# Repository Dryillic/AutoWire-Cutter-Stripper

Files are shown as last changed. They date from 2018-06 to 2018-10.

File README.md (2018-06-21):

# AutoWire-Cutter-Stripper

This repository is for documenting the process and project of creating our own automatic wire cutter.
The device will be able to take input from the user regarding wire length, options and number of wires.

The original inspiration for this project came from Reddit user "Maclsk" on the subreddit /r/specializedtools, link here: https://www.reddit.com/r/specializedtools/comments/78wd32/i_made_a_specialized_tool_for_cutting_wire/
Our goal is to create a similar device with autostripping for our workplace.

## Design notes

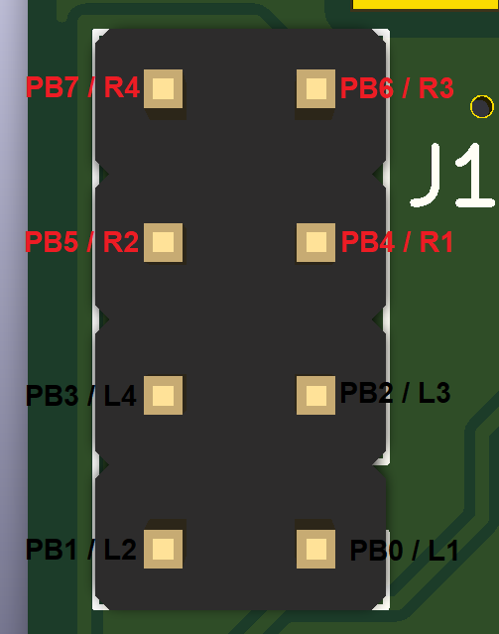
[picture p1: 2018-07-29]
Keypad Pinout.png

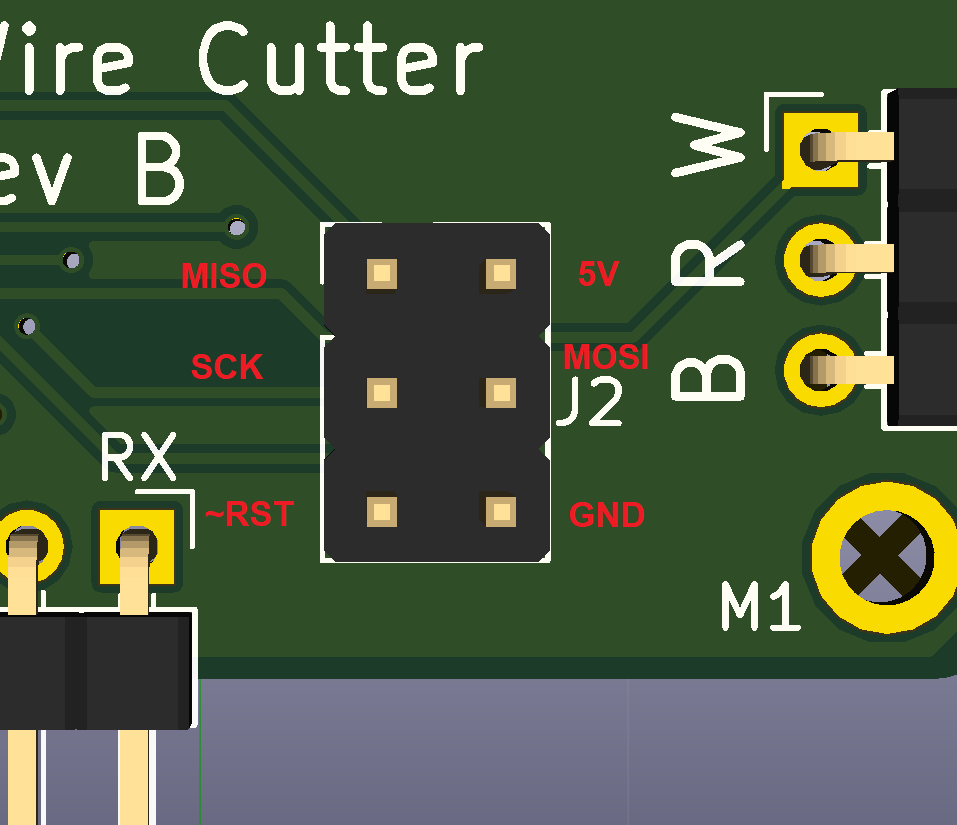
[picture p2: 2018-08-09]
SPI Connections.png

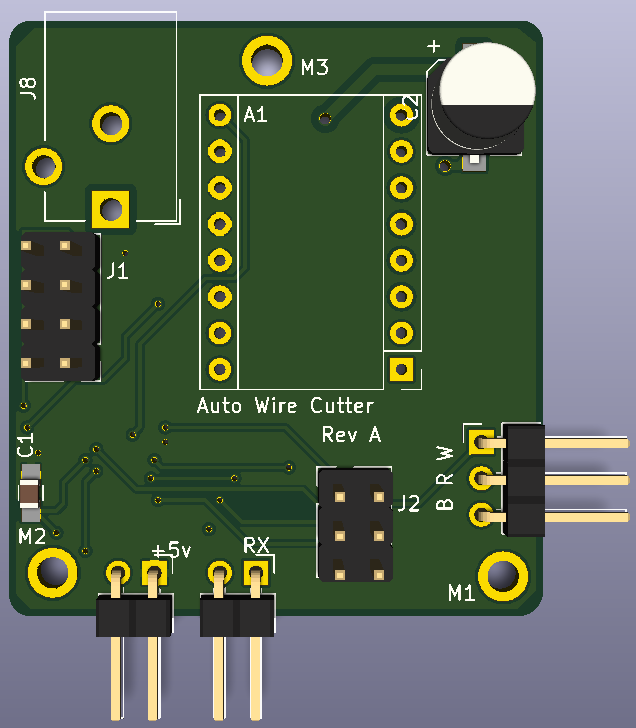
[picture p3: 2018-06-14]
Board Top.png

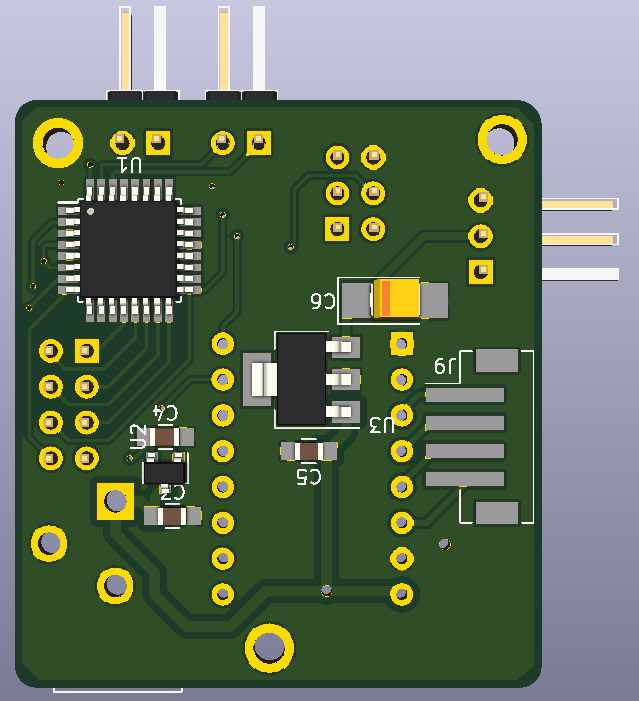
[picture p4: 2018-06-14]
Board Bottom.png

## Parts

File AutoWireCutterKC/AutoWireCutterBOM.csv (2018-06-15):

Source: | C:/Users/dnatov/Documents/GitHub/AutoWire-Cutter-Stripper/AutoWireCutterKC/AutoWireCutterKC.sch
Date: | 6/14/2018 12:04
Tool: | Eeschema 4.0.7
Generator: | C:/Program Files (x86)/KiCad/bin/scripting/plugins/bom_csv_grouped_by_value.py
Component Count: | 20
Individual Components:
Item | Qty | Reference(s) | Value | LibPart | Footprint | Datasheet
 |  | A1 | Pololu_Breakout_DRV8825 | Driver_Motor:Pololu_Breakout_DRV8825 | Module:Pololu_Breakout-16_15.2x20.3mm
 |  | C1 | 100n | device:C | Capacitors_SMD:C_0805_HandSoldering
 |  | C2 | 100u | device:CP | Capacitors_SMD:CP_Elec_6.3x7.7
 |  | C3 | 1u | device:C | Capacitors_SMD:C_0805_HandSoldering
 |  | C4 | 1u | device:C | Capacitors_SMD:C_0805_HandSoldering
 |  | C5 | 1u | device:C | Capacitors_SMD:C_0805_HandSoldering
 |  | C6 | 3.3u | device:CP1 | Capacitors_Tantalum_SMD:CP_Tantalum_Case-B_EIA-3528-21_Hand
 |  | J1 | LCD I/O | conn:Conn_01x08 | Pin_Headers:Pin_Header_Straight_2x04_Pitch2.54mm
 |  | J2 | ISP | conn:Conn_02x03_Odd_Even | Pin_Headers:Pin_Header_Straight_2x03_Pitch2.54mm
 |  | J3 | LCD Serial | conn:Conn_01x02 | Pin_Headers:Pin_Header_Angled_1x02_Pitch2.54mm
 |  | J5 | LCD Power | conn:Conn_01x02 | Pin_Headers:Pin_Header_Angled_1x02_Pitch2.54mm
 |  | J6 | Servo | conn:Conn_01x03 | Pin_Headers:Pin_Header_Angled_1x03_Pitch2.54mm
 |  | J8 | Barrel_Jack | conn:Barrel_Jack | Connectors:Barrel_Jack_CUI_PJ-102AH
 |  | J9 | Stepper | conn:Conn_01x04 | S4B-PH-SM4-TB
 |  | M1 | Conn_01x01_Male | conn:Conn_01x01_Male
 |  | M2 | Conn_01x01_Male | conn:Conn_01x01_Male
 |  | M3 | Conn_01x01_Male | conn:Conn_01x01_Male
 |  | U1 | ATMEGA328P-AU | atmel:ATMEGA328P-AU | Housings_QFP:TQFP-32_7x7mm_Pitch0.8mm
 |  | U2 | MCP1700_SOT23 | regul:MCP1700-5002E_SOT23 | TO_SOT_Packages_SMD:SOT-23
 |  | U3 | LT1129-5.0_SOT223 | regul:LT1129-5.0_SOT223 | TO_SOT_Packages_SMD:SOT-223
Collated Components:
Item | Qty | Reference(s) | Value | LibPart | Footprint | Datasheet
1 | 1 | A1 | Pololu_Breakout_DRV8825 | Driver_Motor:Pololu_Breakout_DRV8825 | Module:Pololu_Breakout-16_15.2x20.3mm
2 | 1 | C1 | 100n | device:C | Capacitors_SMD:C_0805_HandSoldering
3 | 1 | C2 | 100u | device:CP | Capacitors_SMD:CP_Elec_6.3x7.7
4 | 3 | C3, C4, C5 | 1u | device:C | Capacitors_SMD:C_0805_HandSoldering
5 | 1 | C6 | 3.3u | device:CP1 | Capacitors_Tantalum_SMD:CP_Tantalum_Case-B_EIA-3528-21_Hand
6 | 1 | J1 | LCD I/O | conn:Conn_01x08 | Pin_Headers:Pin_Header_Straight_2x04_Pitch2.54mm
7 | 1 | J2 | ISP | conn:Conn_02x03_Odd_Even | Pin_Headers:Pin_Header_Straight_2x03_Pitch2.54mm
8 | 1 | J3 | LCD Serial | conn:Conn_01x02 | Pin_Headers:Pin_Header_Angled_1x02_Pitch2.54mm
9 | 1 | J5 | LCD Power | conn:Conn_01x02 | Pin_Headers:Pin_Header_Angled_1x02_Pitch2.54mm
10 | 1 | J6 | Servo | conn:Conn_01x03 | Pin_Headers:Pin_Header_Angled_1x03_Pitch2.54mm
11 | 1 | J8 | Barrel_Jack | conn:Barrel_Jack | Connectors:Barrel_Jack_CUI_PJ-102AH
12 | 1 | J9 | Stepper | conn:Conn_01x04 | Pin_Headers:Pin_Header_Straight_1x04_Pitch2.54mm
13 | 3 | M1, M2, M3 | Conn_01x01_Male | conn:Conn_01x01_Male
14 | 1 | U1 | ATMEGA328P-AU | atmel:ATMEGA328P-AU | Housings_QFP:TQFP-32_7x7mm_Pitch0.8mm
15 | 1 | U2 | MCP1700_SOT23 | regul:MCP1700-5002E_SOT23 | TO_SOT_Packages_SMD:SOT-23
16 | 1 | U3 | LT1129-5.0_SOT223 | regul:LT1129-5.0_SOT223 | TO_SOT_Packages_SMD:SOT-223

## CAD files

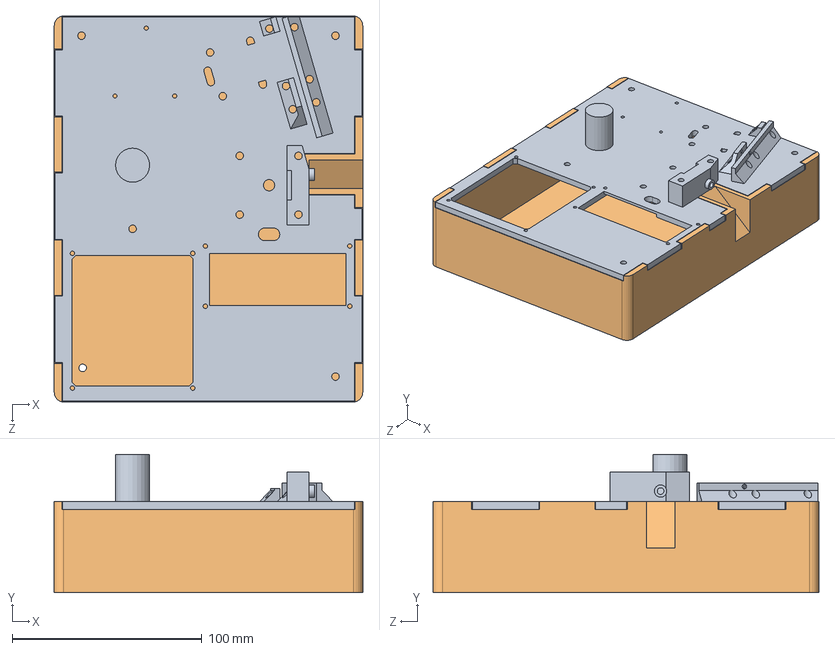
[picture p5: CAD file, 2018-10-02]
CAD Models/AutoWireCutter Assem.SLDASM
162.8 x 73.0 x 203.7 mm
Base Plate
Base

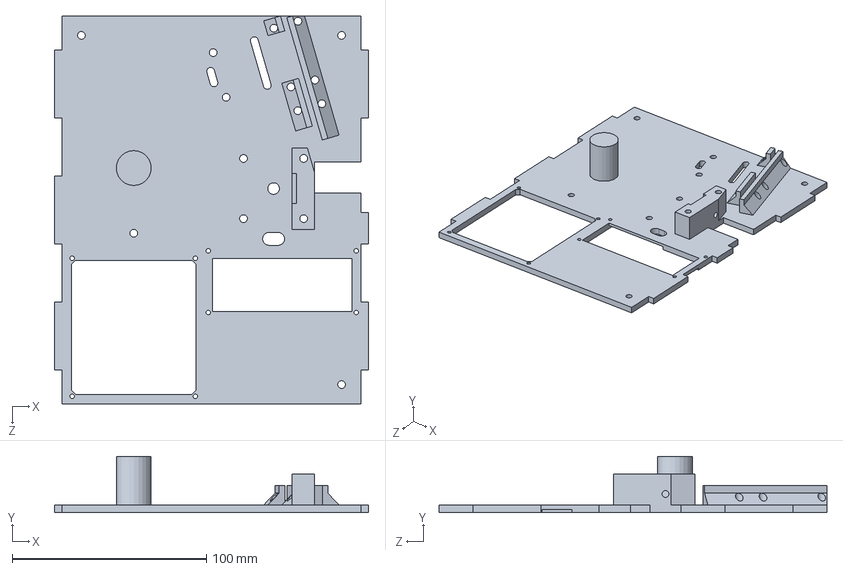
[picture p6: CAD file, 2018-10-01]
CAD Models/Base Plate Assembly.SLDPRT
162.0 x 29.0 x 199.9 mm

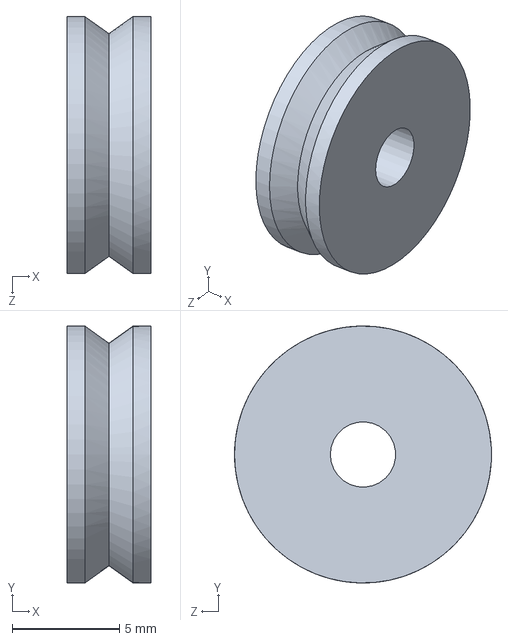
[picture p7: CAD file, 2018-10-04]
CAD Models/Idler.SLDPRT
3.94 x 12.0 x 12.0 mm

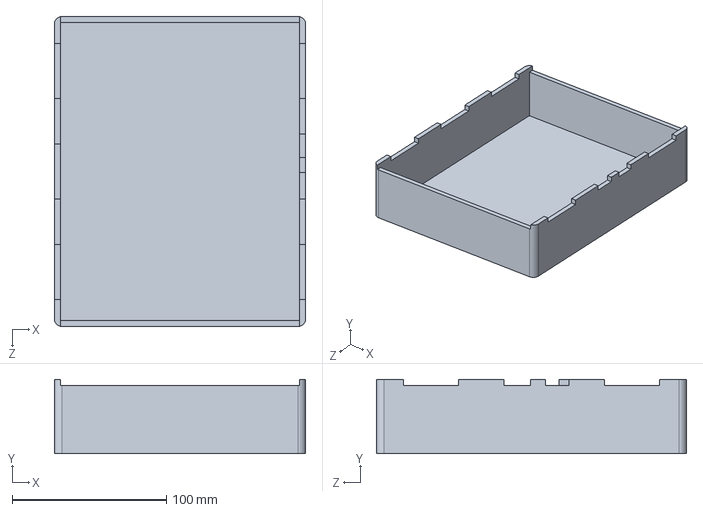
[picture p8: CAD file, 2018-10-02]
CAD Models/Base.SLDPRT
162.8 x 48.0 x 200.7 mm

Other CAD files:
CAD Models/Base Plate.SLDPRT
CAD Models/Base Plate.STL
CAD Models/Base.STL
CAD Models/Idler.STL

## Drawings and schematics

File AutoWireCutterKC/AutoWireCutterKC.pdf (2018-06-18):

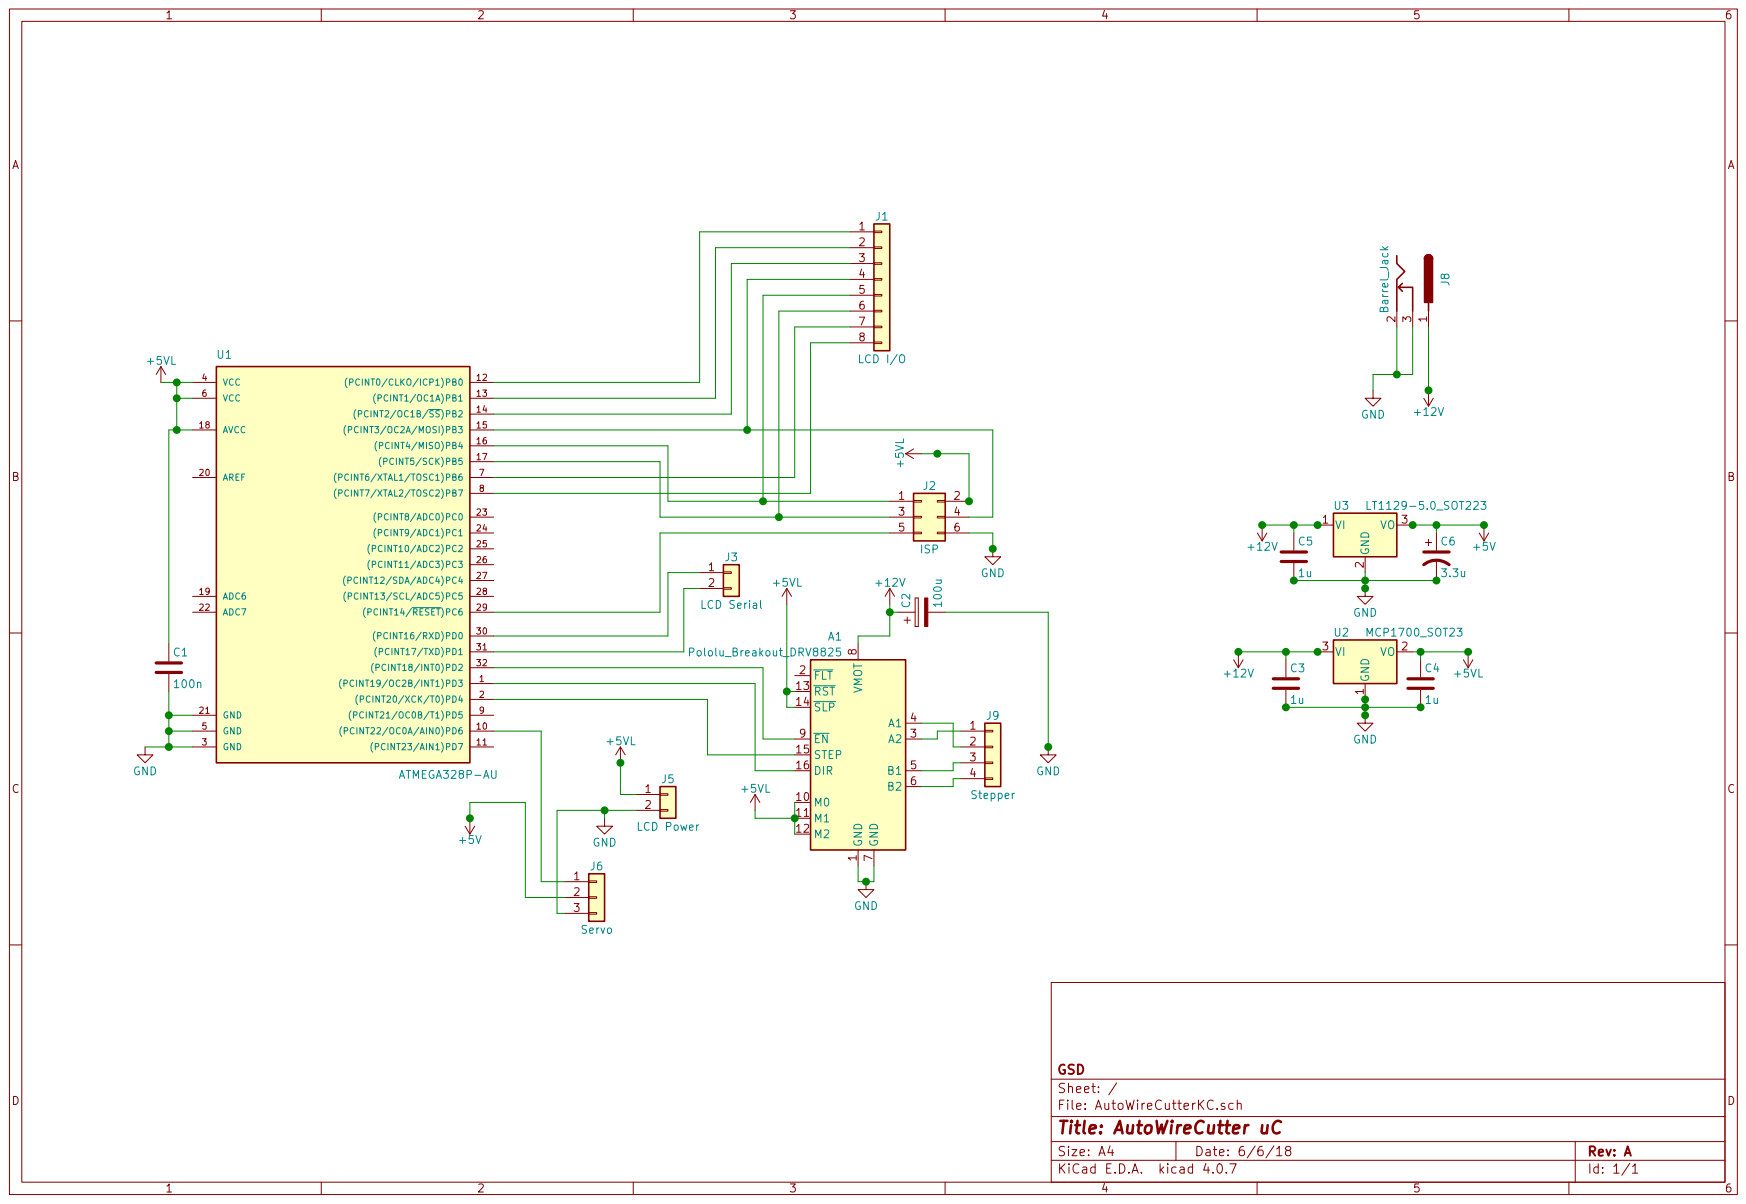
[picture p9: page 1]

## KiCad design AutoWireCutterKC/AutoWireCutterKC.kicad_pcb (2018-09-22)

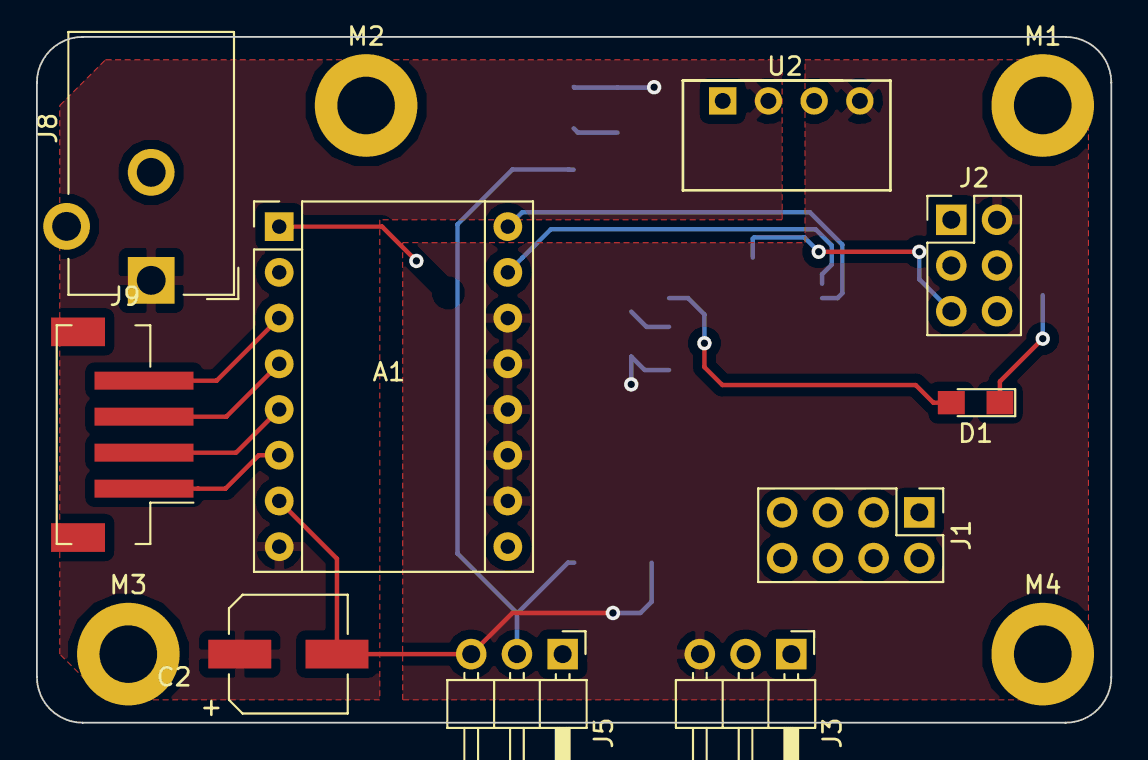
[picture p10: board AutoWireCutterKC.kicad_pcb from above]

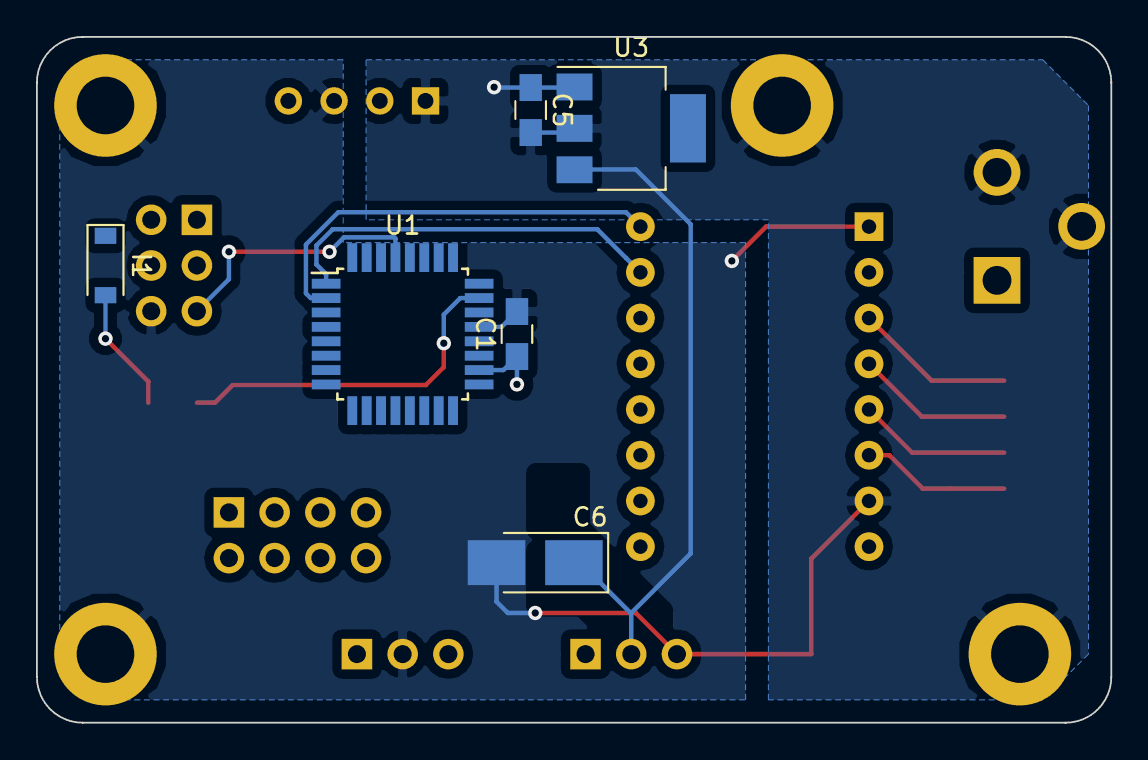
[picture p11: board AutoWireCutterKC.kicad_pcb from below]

Board: 2 copper layers, 59.7 x 38.1 mm, 20 parts (6 on the bottom side), 25 nets.

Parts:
A1: Pololu_Breakout_DRV8825; Pololu_Breakout-16_15.2x20.3mm
C1: 100n; C_0805_HandSoldering
C2: 100u; CP_Elec_6.3x7.7
C5: 1u; C_0805_HandSoldering
C6: 3.3u; CP_Tantalum_Case-B_EIA-3528-21_Hand
D1: LED; LED_0805_HandSoldering
I1: NSI50010YT1G; D_SOD-123
J1: LCD I/O; Pin_Header_Straight_2x04_Pitch2.54mm
J2: ISP; Pin_Header_Straight_2x03_Pitch2.54mm
J3: LCD; Pin_Header_Angled_1x03_Pitch2.54mm
J5: Servo; Pin_Header_Angled_1x03_Pitch2.54mm
J8: Barrel_Jack; Barrel_Jack_CUI_PJ-102AH
J9: Stepper; JST_PH_B4B_StressReliefCorrect
M1, M2, M3, M4: Conn_01x01_Male; MountingHole_3.2mm_M3_ISO7380_Pad
U1: ATMEGA328P-AU; TQFP-32_7x7mm_Pitch0.8mm
U2: CRE1S1205SC; CRE1S1205SC_DC_to_DC
U3: LT1129-5.0_SOT223; SOT-223

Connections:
+5V: C6.1, J5.2, U3.3
+5VL: A1.10, A1.11, A1.12, A1.13, A1.14, C1.1, J2.2, J3.3, U1.4, U1.6, U1.18, U2.4
+12V: A1.8, C2.1, C5.1, J8.1, U2.2, U3.1
GND: A1.7, C2.2, C5.2, C6.2, I1.1, J5.3, J8.2, J8.3, M2.1, M3.1, U2.1, U3.2
GNDREF: A1.1, C1.2, J2.6, J3.2, M1.1, M4.1, U1.3, U1.5, U1.21, U2.3
unnamed: A1.3, J9.4
unnamed: A1.4, J9.3
unnamed: A1.5, J9.2
unnamed: A1.6, J9.1
unnamed: A1.9, U1.32
unnamed: A1.15, U1.1
unnamed: A1.16, U1.2
unnamed: D1.1, I1.2
unnamed: D1.2, U1.23
unnamed: J1.1, U1.12
unnamed: J1.2, U1.13
unnamed: J1.3, U1.14
unnamed: J1.4, J2.4, U1.15
unnamed: J1.5, J2.1, U1.16
unnamed: J1.6, J2.3, U1.17
unnamed: J1.7, U1.7
unnamed: J1.8, U1.8
unnamed: J2.5, U1.29
unnamed: J3.1, U1.31
unnamed: J5.1, U1.10

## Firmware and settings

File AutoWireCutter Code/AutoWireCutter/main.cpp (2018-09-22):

/*
 * AutoWireCutter.cpp
 *
 * Created: 7/29/2018 12:19:06 PM
 * Authors : Dana Natov, Keith Tulley
 * 
 */ 

#define F_CPU 8000000UL /* 8Mhz clock rate */
#define BAUD 2400
#define USART_BAUDRATE 2400
#define BAUD_PRESCALE (((F_CPU / (USART_BAUDRATE * 16UL))) - 1)
#define display_On 0x16 /*  Parralax cmd: Display on with no cursor and no blink */
#define first_position 0x80 /* Parralax cmd: Move cursor to line 0 position 0 */
#define form_feed 0x0C /* Parralax cmd: Clear all text, move to line 0 pos 0 */
#define line_feed 0x0A /* Parralax cmd: Cursor moved to next line */
#define backlight_on 0x11 /* Parralax cmd: LCD Backlight on */
#define backlight_off 0x12 /* Parralax cmd: LCD Backlight off */
volatile int button_down;
#define BUTTON_MASK (1<<PB4)  //	Keypad input, R1 on Blue Keypad
#define BUTTON_MASK1 (1<<PB5) //	Keypad input, R2 on Blue Keypad
#define BUTTON_MASK2 (1<<PB6) //	Keypad input, R3 on Blue Keypad
#define BUTTON_MASK3 (1<<PB7) //	Keypad input, R4 on Blue Keypad
#define BUTTON_PIN PINB

#include <util/delay.h>
#include <avr/io.h>
#include <stdio.h>
#include "Servo.h"
#include "DRV8825.h"

static inline void ser_init() /* I'm told Static Inline functions are great for things that are called once (like initializing serial) */
{
	UCSR0B = (1 << TXEN0) | (1 << RXEN0); /* Serial Transmit and Recieve Enable */
	UCSR0C = (0 << USBS0) | (3 << UCSZ00); /* Set Stop Bit Length (1 Stop Bit) and Frame Length (8 data bits). No parity */
	UBRR0H = (unsigned char)(BAUD_PRESCALE >> 8); /* Load upper 8-bits of baud rate value into high byte of UBBR0 register */
	UBRR0L = (unsigned char)BAUD_PRESCALE; /* Load lower 8-bits of the baud rate value into low byte of UBBR0 register */
	while ( !( UCSR0A & (1 << UDRE0)));
	; /* Wait for an empty Transmit Buffer */
	UDR0 = display_On; /* Turn LCD on with no blink and no cursor */
	
}

static inline void debounce(void)
{
	// Counter for number of equal states
	static uint8_t count = 0;
	// Keeps track of current (debounced) state
	uint8_t button_state = 0;

	// Check if button is high or low for the moment
	uint8_t current_state = ((~BUTTON_PIN & BUTTON_MASK) | (~BUTTON_PIN & BUTTON_MASK1) | (~BUTTON_PIN & BUTTON_MASK2) | (~BUTTON_PIN & BUTTON_MASK3)) != 0; // This is what allows multiple buttons to be debounced
	
	
	// Original Debounce
	if (current_state != button_state) {
		// Button state is about to be changed, increase counter
		count++;
		if (count >= 4) {
			// The button have not bounced for four checks, change state
			button_state = current_state;
			// If the button was pressed (not released), tell main so
			if (current_state != 0) {
				button_down = 1;
			}
			count = 0;
		}
		} else {
		// Reset counter
		count = 0;
	}
}

unsigned char keypad(void){	// Define the function to return which key is pressed
	unsigned char key;	//which key is pressed?
	unsigned char portb_pin;
	
	unsigned char keypad_column[4] = {7,6,5,4};	//Pins b7, 6, 5, 4 of Port B control keypad columns
	unsigned char keypad_row[4] = {3,2,1,0};	// Pins b3, 2, 1, 0 of Port B control keypad rows
	unsigned char keypad_array[4][4] ={	//Array contains all
		{'1','2','3','A'},
		{'4','5','6','B'},
		{'7','8','9','C'},
		{'*','0','#','D'}
	};
	unsigned char column;
	unsigned char row;

	
	for (column=0; column<4; column++){	//
		PORTB = ~(1<<(keypad_column[column]));
		_delay_ms(20);
		portb_pin = PINB;	//read the value from port B
		for(row=0; row<4; row++){
			if((portb_pin & (1<<(keypad_row[row])))==0) {
				key = keypad_array[column][row];	// search for the corresponding element in keypad array
				return (key);	// return the answer, which key is pressed?
			}
		}
	}
}



int printCHAR(char character, FILE *stream) /* Has printchar become a stream */
{
	

	while ((UCSR0A & (1 << UDRE0)) == 0) {}; /* While the transmit flag is active, the serial buffer is a character */

	UDR0 = character;

	return 0;
}

/*C only function that should have been included in compiler by now, 
check out http://savannah.nongnu.org/bugs/?36970. Function call moved to Main
for proper scope*/
//FILE uart_str = FDEV_SETUP_STREAM(printCHAR, NULL, _FDEV_SETUP_RW); /* Sets up "printf" */

int main(void)
{
	static FILE uart_str;
	fdev_setup_stream(&uart_str,printCHAR,NULL,_FDEV_SETUP_WRITE);
	
	DDRB = 0xF0;	//Configure Port B, Pins b7 to b4 are output. Pins b3 to b0 are input.
	// CTC for Timer 2 Setup
	//Edit by Dana, Set Timer to NOT use pin toggle, very important for proper Stepper function
	TCCR2A |= (1<<WGM21);	// Configure Timer 2 to CTC (Clear on timer compare) mode?????????????????????????????
	OCR2A = 260; // Set CTC Value for ~30HZ (From (8mHz Clock / 1024 prescaler) / (target of 30 HZ) = ~260)
	TCCR2B |= ((1<<CS20) | (1<<CS21) | (1<<CS22)); 	// Setup Timer for 8 mHz with a 1024 prescale
	
	// UART Link
	stdout = &uart_str; /* Links stdout and stream from file we set up */
	
	// Serial Init, LCD Backlight on
	ser_init(); /* Serial Initialize */
	UDR0 = backlight_on; /* Turn on LCD backlight */
	
	//Create Servo Object and Init
	Servo MainServo;
	MainServo.Intialize();
		
	//Create Stepper Object and Init
	DRV8825 MainStepper;
	MainStepper.Initialize();
	
	_delay_ms(1000);
	
	//Set External Interrupts
	sei();
	
	// Scratchpad variable
	int digit;	/* Temporary variable to hold the value of which key is pressed */

	//Init LCD splash screen
	!( UCSR0A & (1 << UDRE0));
	UDR0 = form_feed;
	_delay_ms(5);
	UDR0 = backlight_on;
	printf("Welcome!");
	
	while(1)
	{
		if (TIFR2 & (1<<OCF2A)) // If the CTC Throws it's flag at OCF2A (Your timer has elapsed)
		{
			debounce();
			
			if (button_down)
			{
				//printf("Hello");
				button_down = 0;
				digit = keypad();	/* Call the  function "keypad" to return the value of key pressed, and hold it with variable "digit" */
				switch(digit) /* Now evaluate value of "digit" to match with the LED pattern needed to be exported to Port B */
				{
					case '0':
						MainStepper.Runtostep(6400,true);
						_delay_ms(200);
						while ( !( UCSR0A & (1 << UDRE0))); /* Wait for serial buffer to clear, clear screen, turn on backlight, display text */
						UDR0 = form_feed;
						_delay_ms(5);
						UDR0 = backlight_on;
						printf("Rotating Stepper!");
						break;
					case '1':
					case '2':
					case '3':
					case '4':
					case '5':
					case '6':
					case '7':
						while ( !( UCSR0A & (1 << UDRE0))); /* Allows cases 1-7 to fall through the switch-case */
						UDR0 = form_feed;
						_delay_ms(5);
						UDR0 = backlight_on;
						printf("The # is:\r");
						printf("%c", digit);
						_delay_ms(50);
						break;
					case '8':
						MainServo.Enable(true);
						_delay_ms(200);
						MainServo.MoveToAngle(100);
						_delay_ms(200);
						MainServo.Enable(false);
						while ( !( UCSR0A & (1 << UDRE0))); /* Wait for serial buffer to clear, clear screen, turn on backlight, display text */
						UDR0 = form_feed;
						_delay_ms(5);
						UDR0 = backlight_on;
						printf("Rotating Servo!");
						break;
					case '9':
						while ( !( UCSR0A & (1 << UDRE0))); /* Wait for serial buffer to clear, clear screen, turn on backlight, display text */
						UDR0 = form_feed;
						_delay_ms(5);
						UDR0 = backlight_on;
						printf("The # is:\r");
						printf("%c", digit);
						_delay_ms(50);
						break;
					
					case 'A':
					case 'B':
					case 'C':
					case 'D':
					case '*':
					case '#':
					while ( !( UCSR0A & (1 << UDRE0))); /* Wait for serial buffer to clear, clear screen, turn on backlight, display text */
					UDR0 = form_feed;
					_delay_ms(5);
					UDR0 = backlight_on;
					printf("The # is:\r");
					printf("%c", digit);
					_delay_ms(50);
					break;
				}
			}
			TIFR2 = (1<<OCF2A); // Clear CTC flag by writing a logic 1 to it
		}	
	}
	return(1);
}

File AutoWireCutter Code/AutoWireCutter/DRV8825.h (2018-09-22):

#pragma once
#include <avr/io.h>
#include <avr/interrupt.h>

volatile long countStepper=0;

class DRV8825 {
	bool enableCont, directionCont;
	bool dir, enbl;
	int stepCount;
	public:
	void Enable(bool);
	void Direction(bool);
	void Initialize();
	void Runtostep(int, bool);
	bool directionRot() {return dir;}
	bool enablestatus() {return enbl;}
};

void DRV8825::Initialize()
{
	PORTD = (1 << PORTD2);
	DDRD |= (1 << PORTD2) | (1 << PORTD3) | (1 << PORTD4); //set ports 2,3,4 to output (6 is output for the servo)
	TCCR1B |= (1 << WGM12); //Set CTC bit timer 1
	OCR1A = 48; //Set tick amount to 48 for 10.5kHz Square Wave, (Toggle output)
	TIMSK1 = (1 << OCIE1A); //Set ISR interrupt
	
	/*note: the timer actually has a frequency of 10.5kHz * 2 = ~21kHz
	The ISR is a port toggle so this frequency has to be double for both rising and falling edges of square wave*/
	
	//SET IN MAIN INSTEAD
	//sei(); //Set I bit. aka set external interrupt
}

void DRV8825::Enable (bool enableCont) { //Enable Stepper Controller uses PORTD2
	if (enableCont) {
		enbl = true;
		PORTD = (0 << PORTD2);
	}
	else {
		enbl = false;
		PORTD = (1 << PORTD2);
	}	
}

void DRV8825::Direction(bool directionCont) { //Set Stepper Direction uses PORTD3
	if (directionCont) { //true is counter-clockwise, the direction the wire normally feeds
	dir = true;
	PORTD = (1 << PORTD3);
	}
	else { //false is clockwise
	dir = false;
	PORTD = (0 << PORTD3);
	}	
}

void DRV8825::Runtostep(int stepCount, bool directionCont) { //200*32 microsteps per revolution meaning 6400 is one revolution
	UCSR0B = (0 << TXEN0) | (0 << RXEN0); /* Serial Transmit and Recieve Disable */
	TCCR1B |= (1 << CS11); //Timer pre-scaler set to div 8 START TIMER
	
	if (countStepper > 2000000000) {
		countStepper = 0;
	}
	long countcurrent = countStepper;
	this->Direction(directionCont);
	while (countStepper < (countcurrent+stepCount+1)) { //+1 to account for setup time when the enable pin goes high
		this->Enable(true);
	}
	this->Enable(false);
	
	TCCR1B |= (0 << CS11); //Timer pre-scaler set to off STOP TIMER
	UCSR0B = (1 << TXEN0) | (1 << RXEN0); /* Serial Transmit and Recieve Enable */
}

ISR(TIMER1_COMPA_vect) //Runs every 10.5khz
{
	countStepper++; //take care not to overflow. Overflows in about 2 days.
	PORTD ^= (1 << PORTD4); //toggle port d4 for square wave
}

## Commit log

2018-01-05 Add files via upload
    Serial Tx/Rx enable for the 328P. Also sets up a stream to serial so "printf" can be used to send ascii to a serial target.
2018-05-20 Added Stepper Library and Test Code
2018-05-20 Added demo video of Stepper Driver
2018-05-26 Create Servo Library Folder
2018-05-26 Added Servo Library and Ex Code
2018-05-26 Move to Stepper Library Folder
2018-05-26 Move ex code to StepperLibrary Folder
2018-06-05 Adding KiCad Files
    [AutoWireCutterKC.kicad_pcb, AutoWireCutterKC.sch]
2018-06-06 Update uC Layout
    Power is next, runout sensor planned.
    [AutoWireCutterKC.sch]
2018-06-11 Schematic Finished
    TODO: Double check connections
    [AutoWireCutterKC.sch]
2018-06-12 Working on footprints
    in progress
    [AutoWireCutterKC.sch]
2018-06-12 Finished Footprints
    Refer to sch for generating BOM
    [AutoWireCutterKC.kicad_pcb, AutoWireCutterKC.sch]
2018-06-12 PCB Populated
    Traces needed
    [AutoWireCutterKC.kicad_pcb, AutoWireCutterKC.sch]
2018-06-12 Moving around footprints
    Changing spacing and connectors
    [AutoWireCutterKC.kicad_pcb]
2018-06-13 PCB Redesign
    Started on traces
    [AutoWireCutterKC.kicad_pcb, AutoWireCutterKC.sch]
2018-06-13 Rewiring - Layout changed again...
    [AutoWireCutterKC.kicad_pcb, AutoWireCutterKC.sch]
2018-06-13 Update bad file
    [AutoWireCutterKC.kicad_pcb]
2018-06-14 Schematic almost done
    [AutoWireCutterKC.kicad_pcb, AutoWireCutterKC.sch]
2018-06-14 Final Version
    Board edge cuts need updating. Otherwise ready to order.
    [AutoWireCutterKC-B.Cu.gbr, AutoWireCutterKC-B.Mask.gbr, AutoWireCutterKC-B.SilkS.gbr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]
2018-06-14 Edge cuts fixed
    [AutoWireCutterKC-B.Cu.gbr, AutoWireCutterKC-B.Mask.gbr, AutoWireCutterKC-B.SilkS.gbr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]
2018-06-14 Added board pictures
    design finalized in OshPark. Ready to order
2018-06-14 BOM Generated
    [AutoWireCutterBOM.csv]
2018-06-15 Rev A
    Updated BOM with missing Footprint
    [AutoWireCutterBOM.csv]
2018-07-01 Add files via upload
    Wirecutter Keypad Debounced, Using Timer 2 (CTC Mode) and with a slow repeat of key when button is held.
2018-07-04 Editing Schematic
    new rev needs more changes
    [AutoWireCutterKC.kicad_pcb]
2018-07-04 Schematic Rev B
    Changed footprint and silk screen issues
    [AutoWireCutterKC.kicad_pcb]
2018-07-04 Schematic Rev B
    Moved silk screen, motor con through holes widened, motor connector fit on top.
    [AutoWireCutterKC.kicad_pcb, AutoWireCutterKC.sch]
2018-07-29 Added Pinout for Keypad, Began schematic work for future boards
    [AutoWireCutterKC.sch]
2018-07-30 Added Main Code
    In Progress. Timer 1 of Stepper needs work.
2018-08-10 In Progress: Changing Schematic
    Rev C
    [AutoWireCutterKC-2018-08-10-14-44-05.sch, AutoWireCutterKC.kicad_pcb, AutoWireCutterKC.sch]
2018-08-20 Board RevC
    Added DC-to-DC converter for isolation, LED for status indication, increased board size and mounting holes and changed pin allocations for more efficient programming.
    [AutoWireCutterKC.kicad_pcb, AutoWireCutterKC.sch]
2018-08-30 Work on PCB layout
    [AutoWireCutterKC.kicad_pcb]
2018-09-20 Reworked Libraries
    Fixed bug involving stepper not rotating. Taking things out of ISR helped. Servo wasn't responding because of incorrect DDRD register
    [AutoWireCutterKC.kicad_pcb]
2018-09-22 Initial CAD Model for Testing
    [Base Plate.SLDPRT, Base Plate.STL]
2018-09-28 CAD Beta
    Functional prototype CAD. Not Final
    [Base Plate.SLDPRT, Base Plate.STL]
2018-09-30 Significant Base Plate Changes
    Hopefully working prototype. Base will be added in the following days.
    [Base Plate.SLDPRT, Base Plate.STL]
2018-10-01 Base Plate Finished. Base needs DC Barrel added
    [AutoWireCutter Assem.SLDASM, Base Plate Assembly.SLDPRT, Base Plate.SLDPRT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]
2018-10-02 Final CAD
    [AutoWireCutter Assem.SLDASM, Base Plate.SLDPRT, Base.SLDPRT]
2018-10-02 Final CAD - Base Missing
    [Base.STL]
2018-10-02 Final CAD - Updated STLs
    [Base Plate.STL]
2018-10-02 Fixed CAD error
    [AutoWireCutter Assem.SLDASM, Base Plate.SLDPRT, Base Plate.STL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]
2018-10-04 Added Custom Idler
    [Idler.SLDPRT, Idler.STL]
